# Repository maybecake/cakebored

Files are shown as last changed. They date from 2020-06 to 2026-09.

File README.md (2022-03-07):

[DESIGN.md](DESIGN.md) for product requirement.

[ENG.md](ENG.md) for eng design.

TODO: Add instructions on how to setup environment and actually generate models.

1. FreeCAD setup with Macro folder pointed to macro folder.
1. (optional) Add convenience macro buttons to tool bars.
1. (optional) VSCode for editing Python macros / helper libraries.

# TODO:
* Add calculations for key base corners to generate connection between neighbor
finger columns.

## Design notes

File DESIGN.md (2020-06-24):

# Cakebored

## Objective

Build a cool, ergo, split keyboard.

Try not to spend too much.

## Features

These are my personal requirements for this keyboard. P number is Priority of the feature, lower is higher priority.

* P0: Custom ergonomic design - parameterized forward kinematic key positioning.
* P0: Split keyboard with thumb clusters.
* P0: Left half can operate as an independent keyboard.
* P0: Programable (i.e. QMK firmware)
* P0: Hot swap key switches
* P0: RGB per key and under lighting.
* P1: USB A hub in keyboard
* P1: Modular 3d print design that allows for some adjustment of parts
* P1: Customizable tilting of halves
* P1: Customizable positioning of thumb clusters
* P1: Socketed micro controller - easily changeable
* P1: Ability to switch to a different microcontroller
* P2: Customizable tilting for individual finger key columns
* P2: Wireless
* P2: Rotary encoder input
* P2: OLED displays
* P2: support non-1u sized keycaps

## Background

It’s COVID-19 quarantine work from home time! I was somehow convinced to get an Ergonox Ez keyboard. 
This led me down a rabbit hole of programmable, ergonomic keyboards. I was not super happy about the 
size and the thumb cluster layout. The [Dactyl Manuform](https://github.com/abstracthat/dactyl-manuform)
layout looks similar but not entirely like something I would like to try out.

### My skills assessment
Here’s my set of skills that led me to believe I can take on this project:

* Programming: advanced
* Embedded programming: intermediate
* 3d design and printing: intermediate to advanced
* Soldering: intermediate
* Electronics design: no experience
* Ordering parts off the internet: intermediate

## Research

This section keeps track of open questions and answered questions while doing research
into parts, libraries and techniques to use.

### Open Questions

#### How does an IO expander work? Dactyl / ergodox uses a teensy 2.0 on the primary side and an MCP23018 16 bit IO Expander on the secondary side.

#### What is I2C? SPI protocols?

#### [Learning how to use KiCAD](https://www.youtube.com/watch?v=c2niS9ZRBHo&list=PL3bNyZYHcRSUhUXUt51W6nKvxx2ORvUQB&index=2)

#### [Learning how to use FreeCAD](https://wiki.freecadweb.org/Getting_started) [programming](https://wiki.freecadweb.org/Macros)

### Answered Questions

#### Should I use some ESP32 controllers I happen to have on hand?

For this first build, keep it simple and use a microcontroller a lot of other people have used, namely, the Arduino pro micro.

#### What are the differences between various 1N4007, 1N4148, etc diodes and which one to use? 

These two have different breakdown characteristics. General consensus on keyboard usage is the 1N4148. There are also other 
[types of diodes](https://www.youtube.com/watch?v=kLX4ZFzzFDg) that should be avoided.

#### Use other fancy inputs or outputs?

Can use encoders (knobs), oled displays.

Stick to basics for this first build.

#### Can I actually solder small SMD components?

Tested this out on an old board I had laying around. Yes, seems doable.

#### Should I harvest old but fully functional mechanical keyboards for parts? (switches, caps)

Lets not do that and just buy new parts.

#### Do I need to panelize the key switch PCB? How do I do this?

No. Turns out that this doesn’t save any money. Also, manufacturers offer panelization options. 
There are also scripts to panelize the design in KiCAD.

#### Do I need to flash both sides of the keyboard if I have a microcontroller on each side?

[Yes, sometimes.](https://docs.splitkb.com/hc/en-us/articles/360011949679-When-do-I-need-to-flash-my-microcontroller-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,already%20when%20you%20get%20it.)

#### Can I make automatic interchangeable primary / secondary and  also independent halves?

Yes, there is [precedence](https://www.reddit.com/r/MechanicalKeyboards/comments/bh1q5y/split_keyboard_underglow_with_interchangable/).

### Microcontrollers

TODO: copy over research from doc.

### Case

#### Key Layout

While the Dactyl and various derivatives (e.g. maniform) seem to be pretty interesting, I want to try a
different, more personalized approach. I also was not interested in learning clojure/openSCAD. Going 
through the FreeCAD Python scripting system, it seems like something that would be easier to pick up and
work with. I also wanted to be able to customize the look of the case, the shape of the various Dactyls
I had seem were not great.

<b>Bonus ideas:</b> use actual keys along the top edge of the keyboard and double as status indicator LED / under 
keyboard glow.

#### Case Features

Want to build a case with modularized components rather than a monolithic single print.

* Possibly make minor repositions the finger key columns and thumb cluster.
* Legs to adjust tenting and angling e.g. Ergdox Ez
* Tray for microcontroller so that it can be replaced or upgraded
* Being able to easily customize where the various TRRS and USB port locations are.

## Build

This section details the ordering of parts and actual build process.

### Electronics

### Case

I have 3d printer, like using PETG, so will use that.

Want to try finishing using an epoxy coat. Purchased some tabletop epoxy.

### Parts List

Per key costs:

| part | vendor | quantity | price | shipping | Per Quant |
|---|---|---|---|---|---|
| switch pcb | jlcpcb | 200 | $15.70 | $9.36  | $0.13 |
| keycaps | aliexpress | 200 | $50.21 | $0.00  | $0.25 |
| switches | kbdfans | 80  | $80.00 | $24.00 | $1.30 |
| hotswap sockets | kbdfans | 200 | $20.00 | | $0.10 |
| 1N4148 diodes | aliexpress | 600 | $5.38  | | $0.01 |
| leds SK6812mini | aliexpress | 300 | $23.92 | | $0.08 |

Per split half keyboard costs:

| part | vendor | quantity | price | shipping | Per Quant |
|---|---|---|---|---|---|
| nuts, bolts, etc | various | 10  | $50.00 | | $5.00  |
| trrs socket | aliexpress | 10  | $10.19 | | $1.02  |
| filament | amazon | 1 | $20.00 | | $20.00 |
| epoxy | amazon | 10  | $40.00 | | $4.00  |
| epoxy color | amazon | 100 | $17.00 | | $0.17  |
| electricity | pg&e | 1 | $10.00 | | $10.00 |
| ic socket | aliexpress | 10  | $1.83  | $2.32 | $0.42  |
| usb cable | aliexpress | 4 | $5.14  | | $1.29  |
| micro controller | aliexpress | 6 | $25.39 | | $4.23  |

Infrastructure costs:

| part | vendor | quantity | price | shipping | Per Quant |
|---|---|---|---|---|---|
| 3d printer |  | 100  | $800.00 |  | $8.00 |
| Soldering Station |  | 1000 | $400.00 |  | $0.40 |

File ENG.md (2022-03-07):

# Eng design

## Keyboard Structure

There are several aspects of the keyboard structure:
1. General shape of the keyboard
1. Key positioning
1. Webbing between each key base

### Coordinate system

Put your left hand flat on the table, the coordinate system looks like this:

```
     | | | |          ^
     | | | |  /       |
     | | | | /        Y
     O O O O        <Z|-X->  (Z is going AWAY from you!)

```

For those, like me, who have trouble mapping coordinates to space, this means:

* Positive X = towards the thumb.
* Positive Y = further away from the user, towards top row of keys.
* Negative Z = higher off the table.
* Using X_AXIS as a rotation vector, negative angles tilt the keys
towards the user.

Since the two half of the keyboard are likely to be symmetrical, only the left
hand needs to be considered. If the two sides are NOT symmetrical, it should be
easy to generate a new layout based on the right hand measurements and just
mirror the final output model.

### Key positioning

There are three types of key positions:
1. Standard below regular finger key columns.
1. Extended key columns for index and pinky fingers.
1. Thumb keys / cluster

General principle is to generate the positioning of all keys based on forward
kinematics.

The finger.py module contains classes that calculate and store the positions for
the keys. Finger measurements are fed into the Finger classes to generate the
positions.

An initial idea was to use differences in finger position and angle to calculate
the angle used to depress a key. However, in practice, this doesn't seem to be
very ~useful~ correct and is overly complicated. A simplified manually entered
angle is used instead.

### Webbing

The individual key structure for retaining the key PCB, switch and key caps were
modeled by hand. (Maybe we should switch to doing this programmatically?). These
key bases all need to joined together to form the 3d shell of the keyboard.

The key_base.py module contains classes that generates this shell based on the
key positions generated from finger.py.

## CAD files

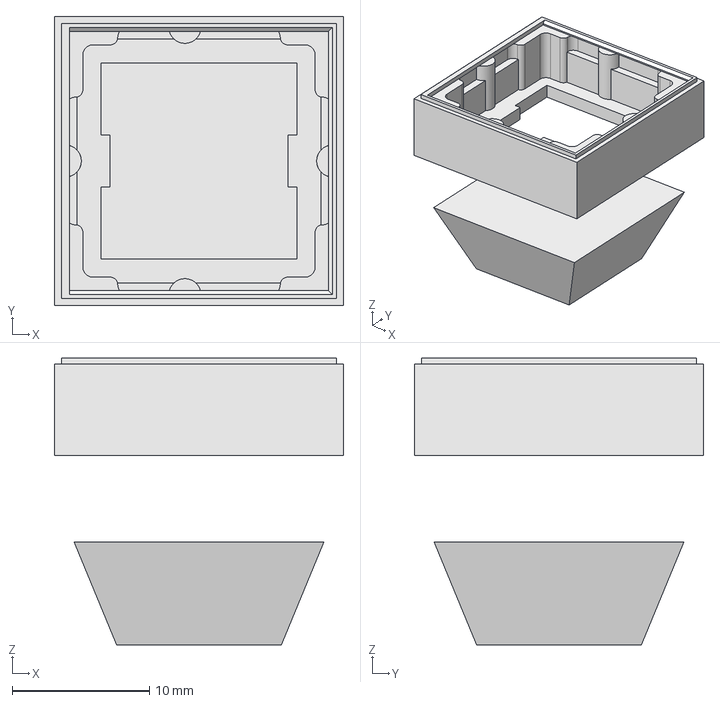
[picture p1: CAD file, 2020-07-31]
freecad/CaseBackup.FCStd
21.1 x 21.1 x 20.9 mm

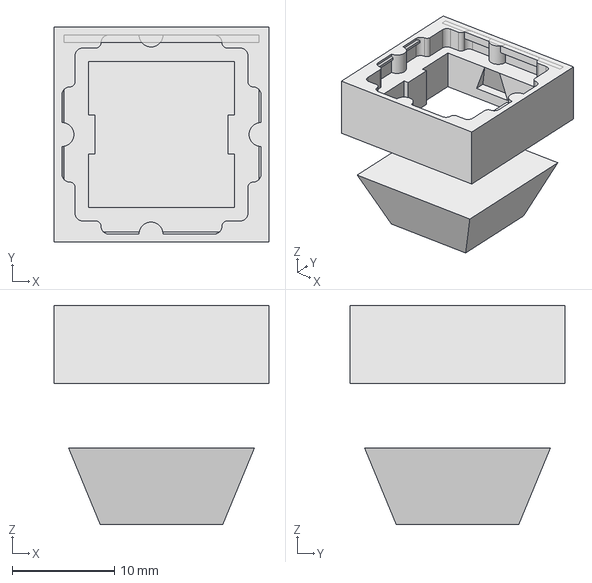
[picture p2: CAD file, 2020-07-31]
freecad/Case.FCStd
21.1 x 21.1 x 21.5 mm

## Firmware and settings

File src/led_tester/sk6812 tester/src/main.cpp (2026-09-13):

#include <Arduino.h>

// put function declarations here:
int myFunction(int, int);

void setup() {
  // put your setup code here, to run once:
  int result = myFunction(2, 3);
}

void loop() {
  // put your main code here, to run repeatedly:
}

// put function definitions here:
int myFunction(int x, int y) {
  return x + y;
}

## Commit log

2020-07-23 initial commit with some basic stuff. C C C
    [Sizing.FCStd, pcb-test.stl, plate-test.stl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]
2020-07-23 Also add stl files to git ignore.
2020-07-23 Redraw PCB shape with 3d printing tolerance var.
    [Sizing.FCStd]
2020-07-23 .gitignore fix
    [pcb-test.stl, plate-test.stl, plate-test2.stl]
2020-07-24 Some random macro exploration and switch enclosure test.
    [Sizing.FCStd, testing.FCStd]
2020-07-24 Clean up single switch enclosure.
    [Case.FCStd, Sizing.FCStd]
2020-07-24 Clean up and reoganize scripts.
    [testing.FCStd]
2020-07-24 make distance from plate to pcb slightly larger so that switch fits completely into plate.
    [Case.FCStd]
2020-07-24 Add a file for testing and development of positioning script.
    [positioning_dev.FCStd]
2020-07-25 clean up and reorganize python files.
    [positioning_dev.FCStd]
2020-07-25 testing position generation from finger parameters.
2020-07-25 Refine model for hand and finger positions.
2020-07-26 Added actuation position calcuation and normalized key positioning.
    [positioning_dev.FCStd]
2020-07-26 Playing with the actual key model.
    [Case.FCStd]
2020-07-26 Add joining keys together into one finger column.
    [Case.FCStd]
2020-07-27 improved v2 for key that hopefully helps with 3d print orientation. Also removed backstop, which can be added in post print finishing.
    [Case.FCStd]
2020-07-27 No longer need special file for testing positioning, just create a new document if needed.
    [positioning_dev.FCStd]
2020-07-31 Add a backstop back to the model. Move README to DESIGN.
    [Case.FCStd, CaseBackup.FCStd]
2023-07-26 Remove debug print.
2023-07-26 Added a sample spinning cube.
2023-07-27 clean up a bit, add button and stats
    Add a create stl button
    Add a stats panel
2026-09-13 Add default led tester project
